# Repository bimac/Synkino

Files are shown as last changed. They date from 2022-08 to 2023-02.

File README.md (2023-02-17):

# SynkinoLC

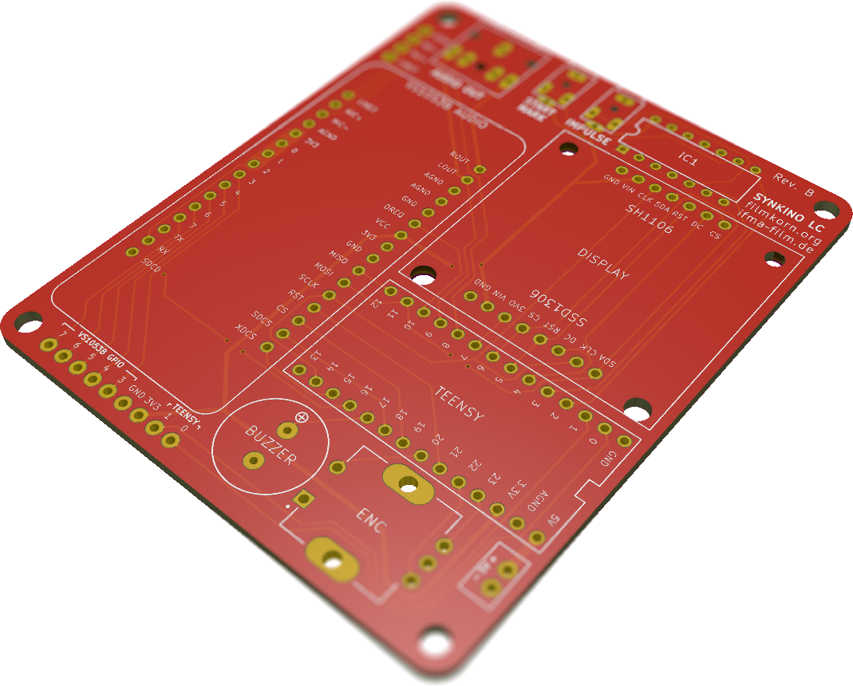
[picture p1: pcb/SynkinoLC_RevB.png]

Allows sound playback synchronised to a running, jittery Super 8 projector.

SynkinoLC started as a fork of [fwachsmuth/Synkino](https://github.com/fwachsmuth/Synkino) with the following changes:

* While the original Synkino utilized two 8-bit ATmega328P microcontrollers (one for the frontend and one for the backend) SynkinoLC incorporates a single, more powerful 32-bit ARM processor through the use of a Teensy microcontroller board.
* Assembly of SynkinoLC is made simple with only a few off-the-shelf components and no SMD soldering required.
* The firmware has been optimized to fit the 62K flash of the Teensy LC microcontroller board (with some limitations), but Teensy 3.2 is also supported and allows for full functionality.
* Unlike the original Synkino, SynkinoLC is not designed for battery operation. Use any micro-USB phone charger as a power supply unit.
* When connected to a host via USB, SynkinoLC provides direct access to its SD card through MTP (Teensy 3.2 only).
* SD cards can be formatted directly from SynkinoLC as either FAT16, FAT32, or ExFAT (Teensy 3.2 only).
* Storing a track numbered 999 (e.g. "999-24.ogg") to the SD card will cause SynkinoLC to automatically start playing it after startup.

Most parts of [Friedemann's manual for the original Synkino](https://www.filmkorn.org/synkino-instruction-manual/?lang=en) apply for SynkinoLC as well.

## Teensy LC vs Teensy 3.2

When building SynkinoLC, you have the option to use either a Teensy LC or Teensy 3.2 microcontroller board. However, as of the time of writing, Teensy 3.2 microcontrollers are unavailable for purchase due to the current global chip shortage. Although the Teensy LC provides ample processing power for SynkinoLC, it has a few minor limitations related to its smaller flash memory of only 62K (compared to 256K on the Teensy 3.2):

* The binary patch file for the VS1053b audio decoder (```patches.053```) cannot be included with the firmware and needs to be supplied by means of the microSD-card.
* You can store settings for "only" 7 projectors (vs 15 on Teensy 3.2).
* The USB stack has been omitted - you can't use debugging by means of USBSerial. You can, however, use the Teensy's HW serial interface (TX on pin 1, 31250 baud).
* SdFat is running in low-mem mode (no support for exFAT, limited to 32GB cards and 64 character filenames).
* No MTP access to the SD card.
* No option for formatting the SD card.

Neither of these limitations should have a significant impact on the usability of SynkinoLC.

## Building the Firmware

SynkinoLC was created with [PlatformIO](https://docs.platformio.org/en/latest/what-is-platformio.htm) for VSCode. To install PlatformIO:

1. [Download](https://code.visualstudio.com/) and install official Microsoft Visual Studio Code. PlatformIO IDE is built on top of it.
2. Open VSCode Package Manager.
3. Search for the official PlatformIO IDE extension.
4. Install PlatformIO IDE.

See [the official guide](https://docs.platformio.org/en/latest/integration/ide/vscode.html) for more details on the VSCode integration.

To build SynkinoLC:
* open ```Synkino.code-workspace```,
* select the respective project environment (```env:teensyLC``` or ```enc:teensy31```), and
* start the build

The firmware won't fit TeensyLC unless ```SD.h``` is modified as outlined [here](https://github.com/PaulStoffregen/SD/pull/44/commits/c3661d2aef4534b5e9cb3a7f66da09e8c61bf286). A pre-build script will attempt to patch this file automatically.

## Choice of OLED display

SynkinoLC has been designed to work with two types of 1.3" OLED display, based on either SH1106 or SSD1306 driver chips:
* An SH1106 display module (as used in the original Synkino) can be obtained for little money on [aliexpress.com](https://aliexpress.com/wholesale?SearchText=sh1106+128+64) (go for the one that says ```1.30"OLED 4-SPI``` on the back). Other SH1106 modules should work as well, as long as they have identical pin-out (the foot-print for the retaining screws might not be an exact fit though).
* Alternatively, you can go for [Adafruit #938](https://octopart.com/938-adafruit+industries-32979003) which is based on an SSD1306 driver (you'll have to cut two traces on the back of the module to enable SPI as demonstrated [here](https://www.youtube.com/watch?v=SXfV4e_jpf8))

Just connect the display module to the respective slot on the SynkinoLC PCB - the firmware will automatically detect the type of display used.

## Bill of Materials

You'll need the following components to assemble SynkinoLC:

| Qty | Part | Description / Comment |
| :-: | :--- | :--- |
|  1  | SynkinoLC PCB | |
|  1  | 1.3" 128x64 monochrome OLED display, SPI | see separate comments above |
|  1  | [Teensy-LC](https://octopart.com/dev-13305-sparkfun-66786787) | microcontroller board |
|  1  | [Adafruit VS1053 Codec + MicroSD Breakout](https://octopart.com/1381-adafruit+industries-32978404) | audio processing board |
|  1  | [Texas Instruments SN74AHC14N](https://octopart.com/sn74ahc14n-texas+instruments-465338) | inverted Schmitt-trigger |
|  2  | [SparkFun ROB-09453](https://octopart.com/rob-09453-sparkfun-67069573) | line sensor breakout (analog) |
|  1  | [Bourns PEC11L-4215F-S0015](https://octopart.com/pec11l-4215f-s0015-bourns-25517430) | rotary encoder |
|  1  | [Cliff CL170842CR](https://octopart.com/cl170842cr-cliff-22810928) (or similar) | knob for rotary encoder |
|  1  | [TDK PS1240P02BT](https://octopart.com/ps1240p02bt-tdk-8602108) | piezo buzzer |
|  2  | [CUI Devices SJ1-2503A](https://octopart.com/sj1-2503a-cui+devices-106235597) | 2.5mm audio jack |
|  2  | [Tensility CA-2203](https://octopart.com/ca-2203-tensility-19254819)  (or similar) | 2.5mm audio cable, stereo |
|  2  | [Sullins PPPC071LFBN-RC](https://octopart.com/pppc071lfbn-rc-sullins-271056) (or similar) | 7 pos female header (for SH1106 display)  |
|  1  | [Sullins PPPC081LFBN-RC](https://octopart.com/pppc081lfbn-rc-sullins-271057) (or similar) | 8 pos female header (for SSD1306 display) |
|  2  | [Sullins PPPC141LFBN-RC](https://octopart.com/pppc141lfbn-rc-sullins-271063) (or similar) | 14 pos female header |
|  2  | [Sullins PPPC181LFBN-RC](https://octopart.com/pppc181lfbn-rc-sullins-271067) (or similar) | 18 pos female header |
|  1  | [Adam Tech PH1-07-UA](https://octopart.com/ph1-07-ua-adam+tech-7873139) (or similar) | 7 pos male header (for SH1106 display) |
|  1  | [Adam Tech PH1-08-UA](https://octopart.com/ph1-08-ua-adam+tech-13205589) (or similar) | 8 pos male header (for SSD1306 display) |
|  2  | [Adam Tech PH1-14-UA](https://octopart.com/ph1-14-ua-adam+tech-14467007) (or similar) | 14 pos male header |

Click [here](https://octopart.com/bom-tool/omFmd0tC) for a full BOM on [octopart.com](https://octopart.com) (with SSD1306 display and not including the PCB). All necessary components should be obtainable for about USD/EUR 80-100 including shipping - depending on your choice of display and PCB service.

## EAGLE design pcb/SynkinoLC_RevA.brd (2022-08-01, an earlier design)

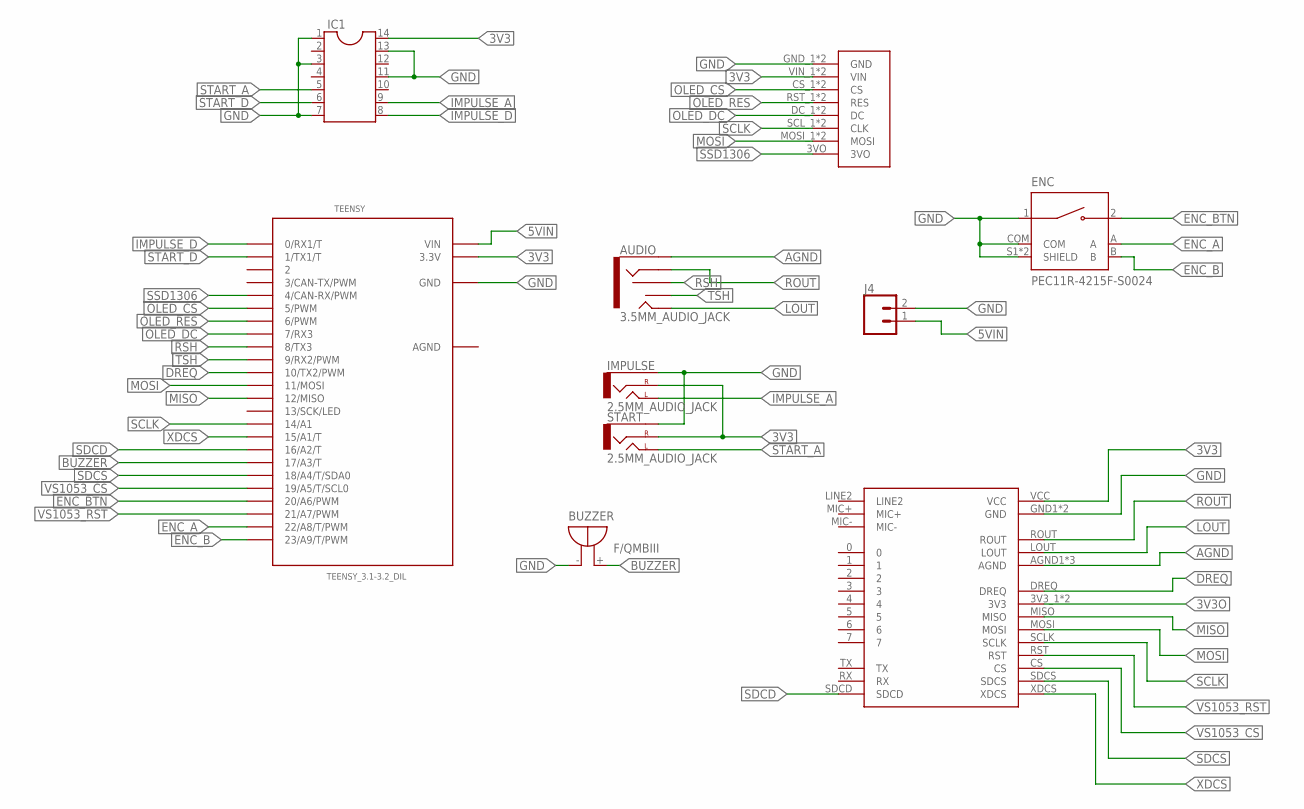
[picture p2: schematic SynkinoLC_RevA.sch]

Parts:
AUDIO: 3.5MM_AUDIO_JACK
BUZZER: F/QMBIII
DISPLAY: SPI_DISPLAY
ENC: PEC11R-4215F-S0024; XDCR_PEC11R-4215F-S0024
IC1: DIL14
IMPULSE: 2.5MM_AUDIO_JACK
J4: CONN_021X02_NO_SILK; 1X02_NO_SILK
START: 2.5MM_AUDIO_JACK
TEENSY: TEENSY_3.1-3.2_DIL; TEENSY_3.0-3.2&LC_DIL
U$2: VS1053B

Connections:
3V3: DISPLAY.VIN_1 (VIN), DISPLAY.VIN_2 (VIN), IC1.14, IMPULSE.RING (RIGHT), START.RING (RIGHT), TEENSY.3.3V, U$2.VCC
3V3O: U$2.3V3_1 (3V3), U$2.3V3_2 (3V3)
5VIN: J4.1, TEENSY.VIN
AGND: AUDIO.SLEEVE, TEENSY.AGND, U$2.AGND1 (AGND), U$2.AGND2 (AGND), U$2.AGND3 (AGND)
BUZZER: BUZZER.+ (-), TEENSY.17/A3 (17/A3/T)
DREQ: TEENSY.10 (10/TX2/PWM), U$2.DREQ
ENC_A: ENC.A, TEENSY.22/A8 (22/A8/T/PWM)
ENC_B: ENC.B, TEENSY.23/A9 (23/A9/T/PWM)
ENC_BTN: ENC.2, TEENSY.20/A6 (20/A6/PWM)
GND: BUZZER.- (+), DISPLAY.GND_1 (GND), DISPLAY.GND_2 (GND), ENC.1, ENC.COM, ENC.S1 (SHIELD), ENC.S2 (SHIELD), IC1.1, IC1.3, IC1.7, IC1.11, IC1.13, IMPULSE.SLEEVE, J4.2, START.SLEEVE, TEENSY.GND, U$2.GND1 (GND), U$2.GND2 (GND)
IMPULSE_A: IC1.9, IMPULSE.TIP_1 (LEFT), IMPULSE.TIP_2 (LEFT)
IMPULSE_D: IC1.8, TEENSY.0 (0/RX1/T)
LOUT: AUDIO.TIP, U$2.LOUT
MISO: TEENSY.12 (12/MISO), U$2.MISO
MOSI: DISPLAY.MOSI_1 (MOSI), DISPLAY.MOSI_2 (MOSI), TEENSY.11 (11/MOSI), U$2.MOSI
OLED_CS: DISPLAY.CS_1 (CS), DISPLAY.CS_2 (CS), TEENSY.5 (5/PWM)
OLED_DC: DISPLAY.DC_1 (DC), DISPLAY.DC_2 (DC), TEENSY.7 (7/RX3)
OLED_RES: DISPLAY.RST_1 (RES), DISPLAY.RST_2 (RES), TEENSY.6 (6/PWM)
ROUT: AUDIO.RING, U$2.ROUT
RSH: AUDIO.RSH, TEENSY.8 (8/TX3)
SCLK: DISPLAY.SCL_1 (CLK), DISPLAY.SCL_2 (CLK), TEENSY.14/A0 (14/A1), U$2.SCLK
SDCD: TEENSY.16/A2 (16/A2/T), U$2.SDCD
SDCS: TEENSY.18/A4 (18/A4/T/SDA0), U$2.SDCS
SSD1306: DISPLAY.3VO, TEENSY.4 (4/CAN-RX/PWM)
START_A: IC1.5, START.TIP_1 (LEFT), START.TIP_2 (LEFT)
START_D: IC1.6, TEENSY.1 (1/TX1/T)
TSH: AUDIO.TSH, TEENSY.9 (9/RX2/PWM)
VS1053_CS: TEENSY.19/A5 (19/A5/T/SCL0), U$2.CS
VS1053_RST: TEENSY.21/A7 (21/A7/PWM), U$2.RST
XDCS: TEENSY.15/A1 (15/A1/T), U$2.XDCS

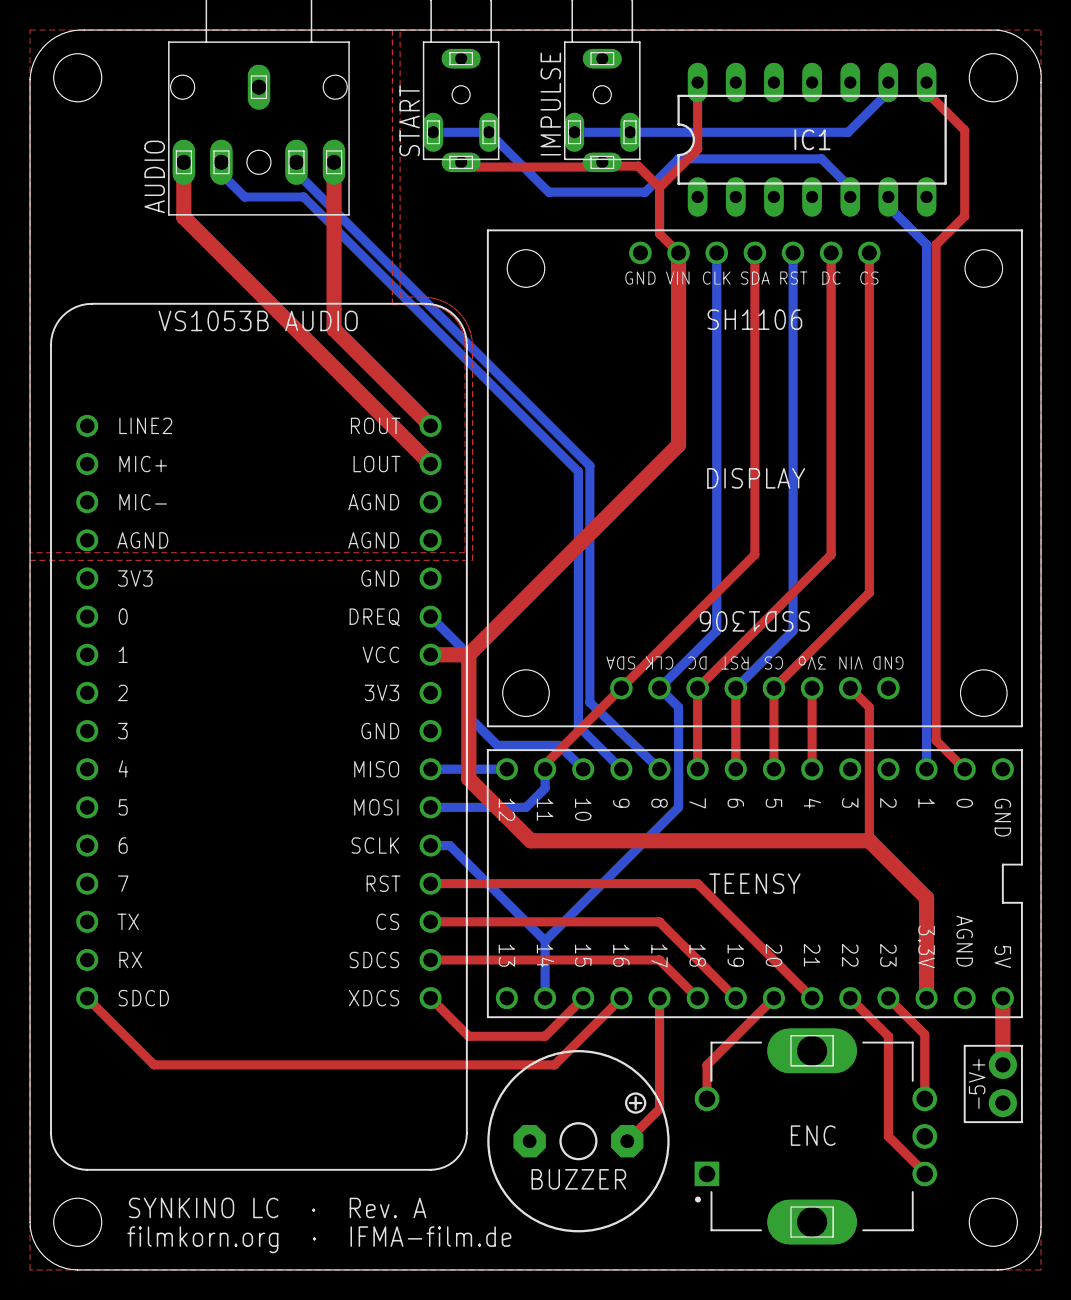
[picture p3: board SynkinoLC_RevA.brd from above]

Board: 2 copper layers, 67.3 x 82.6 mm, 10 parts (0 on the bottom side), 30 nets.

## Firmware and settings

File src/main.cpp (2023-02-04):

const char *uCVersion  = "SynkinoLC v1.0 beta2";
char boardRevision[20] = "Hardware Revision X";   // will be corrected during initialization of VS1053B
#if defined(__MKL26Z64__)
  const char *uC = "Teensy LC";
#elif defined(__MK20DX256__)
  const char *uC = "Teensy 3.1 / 3.2";
#endif

#include <Arduino.h>
#include <U8g2lib.h>
#include "TeensyTimerTool.h"      // hard- and software timers on teensy boards
using namespace TeensyTimerTool;
#include <EncoderTool.h>
using namespace EncoderTool;

#include "serialdebug.h"  // macros for serial debugging
#include "ui.h"           // some UI methods of general use
#include "audio.h"        // all things audio (derived from Adafruit_VS1053_FilePlayer)
#include "buzzer.h"       // the buzzer and some helper methods
#include "projector.h"    // management of the projector configuration & EEPROM storage
#include "pins.h"         // pin definitions
#include "menus.h"        // menu definitions, positions of menu items

#if defined(FORMAT_SD)
#include "formatSD.h"     // include menu option for formatting SD cards
#endif

// Use MTP disk?
#if defined USB_MTPDISK || defined USB_MTPDISK_SERIAL
  #include <SD.h>
  #include <MTP_Teensy.h>
  #define CS_SD VS1053_SDCS
  PeriodicTimer mtpTimer(TCK);
#endif

// Declaration of functions
// See https://docs.platformio.org/en/latest/faq/ino-to-cpp.html
void dimDisplay(bool);
void breathe(bool);
uint8_t u8x8_GetMenuEvent(u8x8_t);

// Initialize Objects
Audio musicPlayer;
U8G2* u8g2;
PolledEncoder enc;
PeriodicTimer encTimer(TCK);
#if defined(__MKL26Z64__)
  OneShotTimer dimmingTimer(TCK);
#else
  OneShotTimer dimmingTimer(TCK64);
#endif
Buzzer buzzer(PIN_BUZZER);
Projector projector;
UI ui;

#define DISPLAY_DIM_AFTER   10s
#define DISPLAY_CLEAR_AFTER 5min
uint8_t myState = MENU_MAIN;

void setup(void) {

  // Initialize serial interface (see serialdebug.h)
  #ifdef MYSERIAL
  MYSERIAL.begin(31250);
  #endif

  // Say hi
  PRINT("Welcome to ");
  PRINTLN(uCVersion);
  PRINTLN("");

  // set pin mode
  pinMode(LED_BUILTIN, OUTPUT);
  pinMode(OLED_DET, INPUT_PULLDOWN);
  pinMode(IMPULSE, INPUT_PULLDOWN);
  pinMode(STARTMARK, INPUT_PULLDOWN);

  // set HW SPI pins
  SPI.setMOSI(SPI_MOSI);
  SPI.setMISO(SPI_MISO);
  SPI.setSCK(SPI_SCK);

  // initialize display / show boot splash
  PRINTLN("Initializing display ...");
  if (digitalReadFast(OLED_DET))
    u8g2 = new U8G2_SSD1306_128X64_NONAME_F_4W_HW_SPI(U8G2_R2, OLED_CS, OLED_DC, OLED_RST);
  else
    u8g2 = new U8G2_SH1106_128X64_NONAME_F_4W_HW_SPI(U8G2_R0, OLED_CS, OLED_DC, OLED_RST);
  u8g2->begin();
  ui.drawSplash();
  dimmingTimer.begin([] { dimDisplay(0); });
  dimmingTimer.trigger(DISPLAY_DIM_AFTER);

  // initialize encoder
  PRINTLN("Initializing encoder ...");
  enc.begin(ENC_A, ENC_B, ENC_BTN, CountMode::half, INPUT_PULLUP);        // Adjust CountMode if necessary
  encTimer.begin([]() { enc.tick(); }, 5_kHz);                            // Poll encoder at 5kHz
  enc.attachCallback([](int position, int delta) { dimDisplay(true); });  // Wake up display on encoder input
  enc.attachButtonCallback([](int state) { dimDisplay(true); });          // Wake up display on button input

  // initialize VS1053B breakout
  while (!musicPlayer.SDinserted())
    ui.showError("Please insert", "SD card");
  switch (musicPlayer.begin()) {
    case 1: ui.showError("Could not initialize", "SD card"); break;
    case 2: ui.showError("Could not initialize", "VS1053B Breakout"); break;
    case 3: ui.showError("Could not apply", "patches.053");
  }
  boardRevision[18] = musicPlayer.getRevision();

  // initialize MTP filesystem
  #if defined USB_MTBDISK || defined USB_MTPDISK_SERIAL
    MTP.addFilesystem(SD, "SD card");
    mtpTimer.begin([]() { MTP.loop(); }, 50_Hz);
  #endif

  // check for autostart file
  if (musicPlayer.loadTrack(999))
    myState = MENU_SELECT_TRACK;

  projector.loadLast();
  PRINTLN("Startup complete.\n");
}

void PULSE_ISR() {
  if (digitalReadFast(IMPULSE)) {
    digitalWriteFast(LED_BUILTIN, HIGH);
    buzzer.play(4400);
  } else {
    digitalWriteFast(LED_BUILTIN, LOW);
    buzzer.quiet();
  }
}

void loop(void) {
  switch (myState) {
  case MENU_MAIN:
    myState = u8g2->userInterfaceSelectionList("Main Menu", 2, main_menu) * 10;
    break;

  case MENU_PROJECTOR:
    myState += u8g2->userInterfaceSelectionList("Projector", 2, projector_action_menu);
    break;

  case MENU_PROJECTOR_NEW:
    projector.create();
    myState = MENU_MAIN;
    break;

  case MENU_PROJECTOR_SELECT:
    projector.load();
    myState = MENU_MAIN;
    break;

  case MENU_PROJECTOR_EDIT:
    projector.edit();
    myState = MENU_MAIN;
    break;

  case MENU_PROJECTOR_DELETE:
    projector.remove();
    myState = MENU_MAIN;
    break;

  case MENU_SELECT_TRACK:
    while (!musicPlayer.selectTrack()) {}
    myState = MENU_MAIN;
    detachInterrupt(STARTMARK);
    digitalWriteFast(LED_BUILTIN, LOW);
    break;

  case MENU_EXTRAS:
    myState += u8g2->userInterfaceSelectionList("Extras", 1, extras_menu);
    break;

  case MENU_EXTRAS_VERSION:
    ui.userInterfaceMessage(uCVersion, boardRevision, uC, " Nice! ");
    myState = MENU_MAIN;
    break;

  case MENU_EXTRAS_IMPULSE:
    attachInterrupt(IMPULSE, PULSE_ISR, CHANGE);
    ui.userInterfaceMessage("Test Impulse", "", "", "Done");
    detachInterrupt(IMPULSE);
    digitalWriteFast(LED_BUILTIN, LOW);
    buzzer.quiet();
    myState = MENU_MAIN;
    break;

#if defined(FORMAT_SD)
  case MENU_EXTRAS_FORMAT_SD:
    formatSD();
    myState = MENU_MAIN;
    break;
#endif

  case MENU_EXTRAS_DEL_EEPROM:
    if (ui.userInterfaceMessage("Delete EEPROM", "Are you sure?", "", " Cancel \n Yes ") == 2)
      projector.e2delete();
    myState = MENU_MAIN;
    break;

#if defined(SERIALDEBUG) || defined(HWSERIALDEBUG)
  case MENU_EXTRAS_DUMP_EEPROM:
    projector.e2dump();
    myState = MENU_MAIN;
    break;
  #endif

  default:
    myState = MENU_MAIN;
  }
}

void dimDisplay(bool activity) {
  static uint8_t c = 255;
  if (activity) {                                             // wake up on activity
    dimmingTimer.trigger(DISPLAY_DIM_AFTER);
    if (c < 255) {
      c = 255;
      u8g2->setContrast(c);
      breathe(false);
    }
  } else if (c > 1) {                                         // smooth dimming
    dimmingTimer.trigger((c>3) ? 10ms : DISPLAY_CLEAR_AFTER);
    u8g2->setContrast(c-=2);
  } else if (myState % 10 == 0 && myState != 20) {            // blank screen & breathing LED (only within main menus)
    u8g2->clearDisplay();
    breathe(true);
  }
}

void breathe(bool doBreathe) {
  static PeriodicTimer tOn(TCK);
  static OneShotTimer  tOff(TCK);
  static int8_t ii = 0;
  if (doBreathe) {
    tOff.begin([] {
      digitalWriteFast(LED_BUILTIN, LOW);
    });
    tOn.begin([] {
      digitalWriteFast(LED_BUILTIN, HIGH);
      tOff.trigger(150*abs(++ii)+1);
    }, 50_Hz);
  } else {
    tOn.stop();
    tOff.stop();
    digitalWriteFast(LED_BUILTIN, LOW);
  }
}

// This overwrites the weak function in u8x8_debounce.c
uint8_t u8x8_GetMenuEvent(u8x8_t *u8x8) {
    yield();

    if (enc.valueChanged()) {
      buzzer.playClick();                         // feedback sound
      int encVal = ui.encDir() * enc.getValue();  // get encoder value
      enc.setValue(0);                            // reset encoder

      if (encVal < 0)
        return U8X8_MSG_GPIO_MENU_UP;
      else
        return U8X8_MSG_GPIO_MENU_DOWN;

    } if (!enc.getButton()) {
      buzzer.playPress();                   // feedback sound
      while (!enc.getButton())              // wait for release
        yield();
      return U8X8_MSG_GPIO_MENU_SELECT;

    } else
      return 0;
}

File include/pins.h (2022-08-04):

#pragma once

#define SPI_MOSI       11
#define SPI_MISO       12
#define SPI_SCK        14  // Alternative pin to bypass the LED on pin 13

#define OLED_DC         4
#define OLED_RST        5
#define OLED_CS         6
#define OLED_DET        7

#define PIN_LOUT        9   // left channel of 3.5mm audio jack (tip position)
#define PIN_TIPSW       8   // switch of 3.5mm audio jack (tip position)

#define VS1053_RST     21   // reset pin
#define VS1053_CS      19   // chip select pin
#define VS1053_DCS     15   // data/command select
#define VS1053_DREQ    10   // data request
#define VS1053_SDCS    18   // SD card chip select
#define VS1053_SDCD    16   // SD card detection

#define ENC_A          23
#define ENC_B          22
#define ENC_BTN        20

#define PIN_BUZZER     17

#define IMPULSE         2
#define STARTMARK       3

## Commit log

2022-06-18 Hello world!
    [breadboard.fzz]
2022-06-18 Adding the encoder
2022-06-22 Add buzzer
    [breadboard.fzz]
2022-07-06 add teensyLC as build target / adapt patch routine
2022-07-06 buzzer freqs as macros
    [SynkinoLC.ino]
2022-07-11 pin definitions for first production run
2022-07-28 menu: avoid nested switch statements
    [SynkinoLC.ino]
2022-08-01 PCB layouts for Revisions A and B
    [SynkinoLC_RevA.brd, SynkinoLC_RevA.sch, SynkinoLC_RevB.brd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]
2022-08-04 various updates V
    - HW serial debugging on TeensyLC
    - work on the PID
    - pin definitions for HW Rev B
2022-08-09 grab bag
    - got rid of all instances of printf()
    - work on the playback UI
    - clean-up
2022-08-17 remove teensy40 build environment
2022-10-01 add offset correction and manual start
    [audio.cpp, main.cpp]
2022-10-05 busy bee better buzz
    [audio.cpp, ui.cpp, xbm.h]
2022-10-25 reset more vars before running PID
    [audio.cpp]
2022-10-25 cleaning up
    [Adafruit VS1053 Breakout.brd, Adafruit VS1053 Breakout.sch, Synkino-BOM.csv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]
2022-10-25 cleaning up some more
    [SynkinoLC_RevA.brd, SynkinoLC_RevA.sch, SynkinoLC_RevB.brd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]
2022-10-25 patch routine currently doesn't work on windows
2022-10-25 more size optimization for teensyLC
2022-10-25 clean up pcb folder
2023-01-17 autostart feature (#2)
    a track numbered 999 will automatically begin playing after start-up
2023-01-17 more size optimizations for TeensyLC and minor corrections
    [main.cpp]
2023-01-31 drive LED low at end of impulse test
2023-01-31 correct PID output limits
    [audio.cpp]
2023-02-02 correction for average() method
    [audio.cpp]
2023-02-04 make sure that buzzer is silenced after an impulse test
    [main.cpp]

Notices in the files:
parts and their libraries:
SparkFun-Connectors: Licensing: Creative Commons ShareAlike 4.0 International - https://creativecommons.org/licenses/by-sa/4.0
